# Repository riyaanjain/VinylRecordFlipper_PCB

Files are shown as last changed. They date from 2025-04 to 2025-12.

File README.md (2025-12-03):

# 🎵 Automatic Vinyl Record Flipper

I love vinyl records.

But each side of a 12 inch LP can only store about 20 minutes of music, and I don't necessarily love having to get up to flip the record often. I just wish that, after I put the record on, it would play the entire album.

So, we took matters into our own hands and built an **automatic vinyl record flipper**.

Included are:
- **PCB Design Files**
- **The program code**
- **A picture and video for your enjoyment (have to download the video from Image_and_Video folder🥲)**
- **Design Document**

Hopefully you enjoy it as much as I did!

---

## 🧠 What It Does

This device automatically flips a vinyl record by sending PWM signals to servo motors using an ESP32 microcontroller. It detects the tonearm rest position using a Hall effect sensor, then triggers the motors to lift, rotate, and drop the record back down.

---

## 🖼️ Project Gallery

### 🔧 PCB Preview  
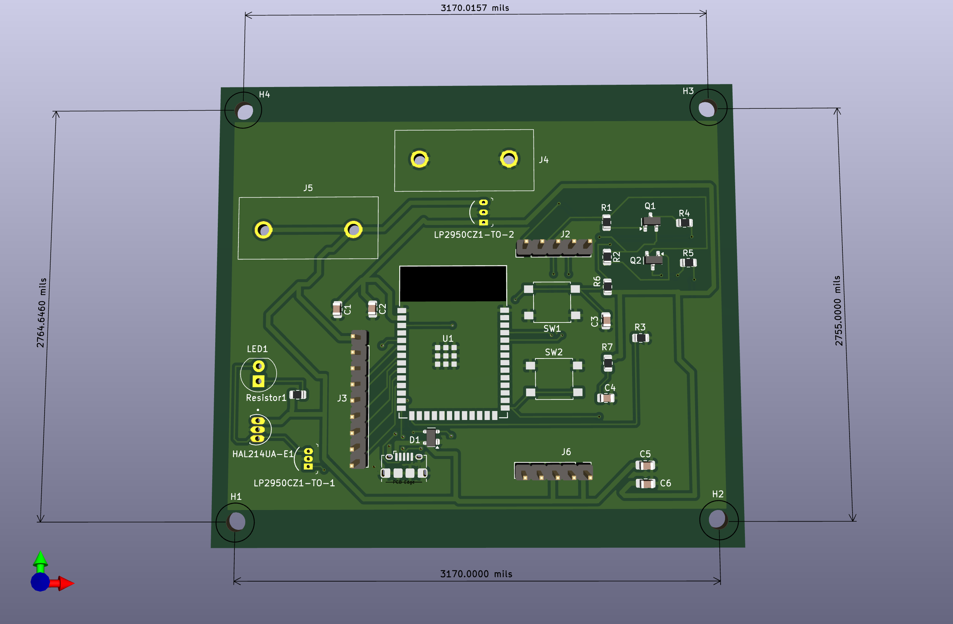
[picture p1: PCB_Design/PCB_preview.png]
PCB Preview


### 📸 Final Project Photo  
Project Photo

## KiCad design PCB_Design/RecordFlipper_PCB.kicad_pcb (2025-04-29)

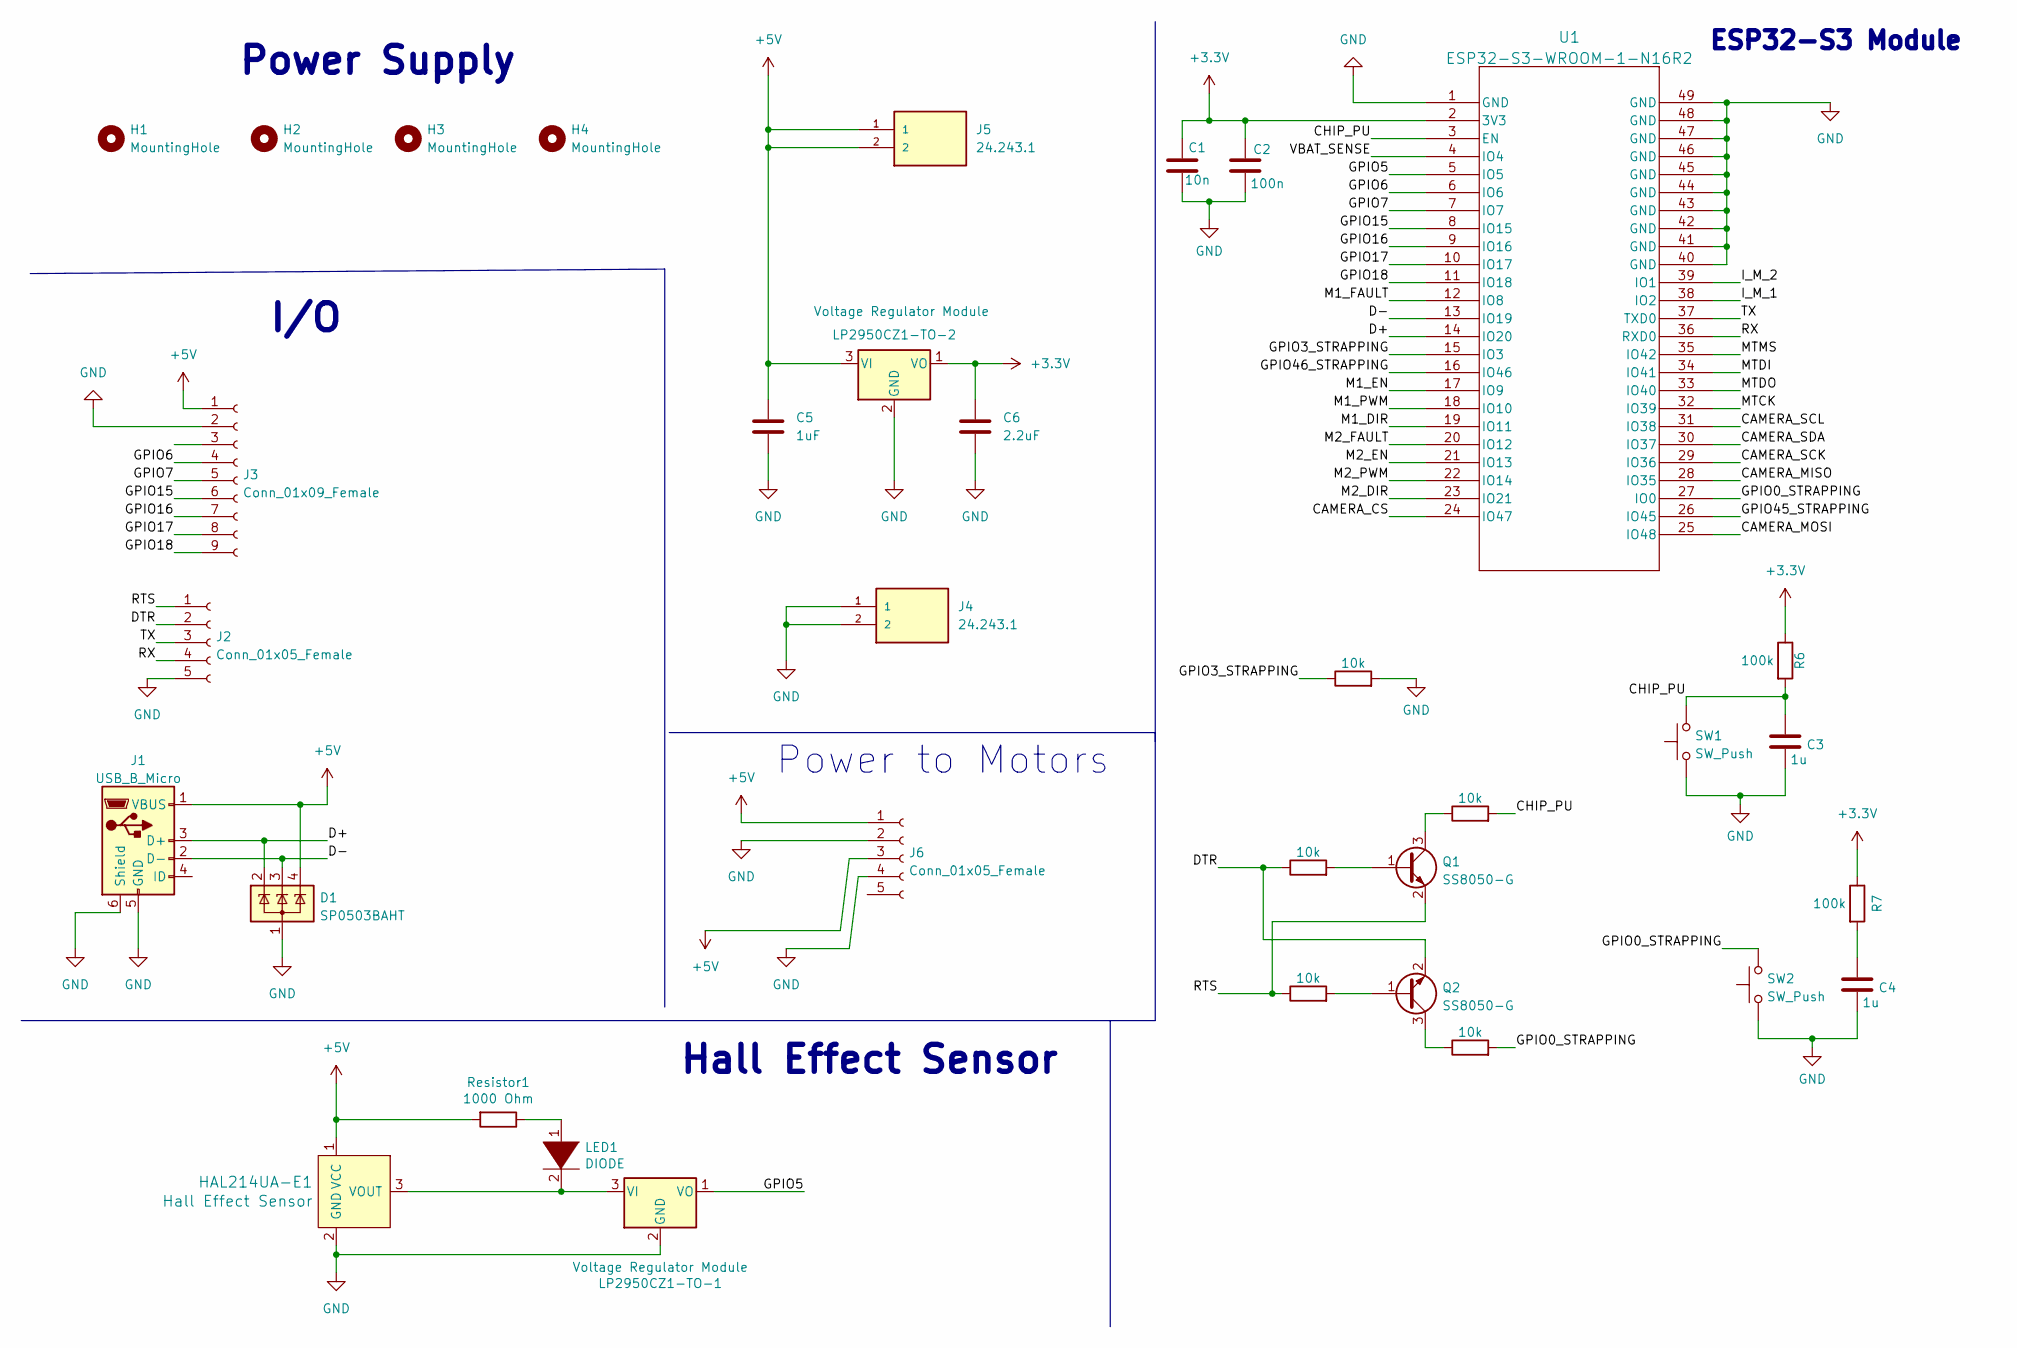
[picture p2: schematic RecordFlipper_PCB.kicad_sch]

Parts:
C1: 10n; C_0805_2012Metric
C2: 100n; C_0805_2012Metric
C3, C4: 1u; C_0805_2012Metric
C5: 1uF; C_0805_2012Metric_Pad1.18x1.45mm_HandSolder
C6: 2.2uF; C_0805_2012Metric_Pad1.18x1.45mm_HandSolder
D1: SP0503BAHT; SOT-143
H1, H2, H3, H4: MountingHole; MountingHole_3.2mm_M3
HAL214UA-E1: Hall Effect Sensor; TO92127P460H470-3; MPN A1326LUA-T; Digi-Key_PN 620-1433-ND
J1: USB_B_Micro; USB_Micro-B_Amphenol_10118194_Horizontal
J2, J6: Conn_01x05_Female; PinHeader_1x05_P2.54mm_Vertical
J3: Conn_01x09_Female; PinHeader_1x09_P2.54mm_Vertical
J4, J5: 24.243.1; 242431; Manufacturer_Part_Number 24.243.1
LED1: DIODE; LED_5mm_Radial
LP2950CZ1-TO-1, LP2950CZ1-TO-2: Voltage Regulator Module; TO-92-3
Q1, Q2: SS8050-G; SOT-23
R1, R2, R3, R4, R5: 10k; R_0805_2012Metric
R6, R7: 100k; R_0805_2012Metric
Resistor1: 1000 Ohm; R_0805_2012Metric
SW1, SW2: SW_Push; SW_SPST_B3S-1000
U1: ESP32-S3-WROOM-1-N16R2; ESP32-S3-WROOM-1_EXP

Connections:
+3.3V: C1.1, C2.1, C6.1, LP2950CZ1-TO-2.1 (VO), R6.1, R7.1, U1.2 (3V3)
+5V: C5.1, D1.4 (K), HAL214UA-E1.1 (VCC), J1.1 (VBUS), J3.1, J5.1, J5.2, J6.1, J6.3, LP2950CZ1-TO-2.3 (VI), Resistor1.2
/CAMERA_CS: U1.24 (IO47)
/CAMERA_MISO: U1.28 (IO35)
/CAMERA_MOSI: U1.25 (IO48)
/CAMERA_SCK: U1.29 (IO36)
/CAMERA_SCL: U1.31 (IO38)
/CAMERA_SDA: U1.30 (IO37)
/CHIP_PU: C3.1, R4.2, R6.2, SW1.2, U1.3 (EN)
/D+: D1.2 (K), J1.3 (D+), U1.14 (IO20)
/D-: D1.3 (K), J1.2 (D-), U1.13 (IO19)
/DTR: J2.2, Q2.2 (E), R1.1
/GPIO0_STRAPPING: R5.2, SW2.2, U1.27 (IO0)
/GPIO3_STRAPPING: R3.1, U1.15 (IO3)
/GPIO5: LP2950CZ1-TO-1.1 (VO), U1.5 (IO5)
/GPIO6: J3.4, U1.6 (IO6)
/GPIO7: J3.5, U1.7 (IO7)
/GPIO15: J3.6, U1.8 (IO15)
/GPIO16: J3.7, U1.9 (IO16)
/GPIO17: J3.8, U1.10 (IO17)
/GPIO18: J3.9, U1.11 (IO18)
/GPIO45_STRAPPING: U1.26 (IO45)
/GPIO46_STRAPPING: U1.16 (IO46)
/I_M_1: U1.38 (IO2)
/I_M_2: U1.39 (IO1)
/M1_DIR: U1.19 (IO11)
/M1_EN: U1.17 (IO9)
/M1_FAULT: U1.12 (IO8)
/M1_PWM: U1.18 (IO10)
/M2_DIR: U1.23 (IO21)
/M2_EN: U1.21 (IO13)
/M2_FAULT: U1.20 (IO12)
/M2_PWM: U1.22 (IO14)
/MTCK: U1.32 (IO39)
/MTDI: U1.34 (IO41)
/MTDO: U1.33 (IO40)
/MTMS: U1.35 (IO42)
/RTS: J2.1, Q1.2 (E), R2.1
/RX: J2.4, U1.36 (RXD0)
/TX: J2.3, U1.37 (TXD0)
/VBAT_SENSE: U1.4 (IO4)
GND: C1.2, C2.2, C3.2, C4.2, C5.2, C6.2, D1.1 (A), HAL214UA-E1.2 (GND), J1.5 (GND), J1.6 (Shield), J2.5, J3.2, J4.1, J4.2, J6.2, J6.4, LP2950CZ1-TO-1.2 (GND), LP2950CZ1-TO-2.2 (GND), R3.2, SW1.1, SW2.1, U1.1 (GND), U1.40 (GND), U1.41 (GND), U1.42 (GND), U1.43 (GND), U1.44 (GND), U1.45 (GND), U1.46 (GND), U1.47 (GND), U1.48 (GND), U1.49 (GND)
unnamed: C4.1, R7.2
unnamed: HAL214UA-E1.3 (VOUT), LED1.2 (A), LP2950CZ1-TO-1.3 (VI)
unnamed: LED1.1 (K), Resistor1.1
unnamed: Q1.1 (B), R1.2
unnamed: Q1.3 (C), R4.1
unnamed: Q2.1 (B), R2.2
unnamed: Q2.3 (C), R5.1

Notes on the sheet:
Hall Effect Sensor
ESP32-S3 Module
Power to Motors
Power Supply
I/O

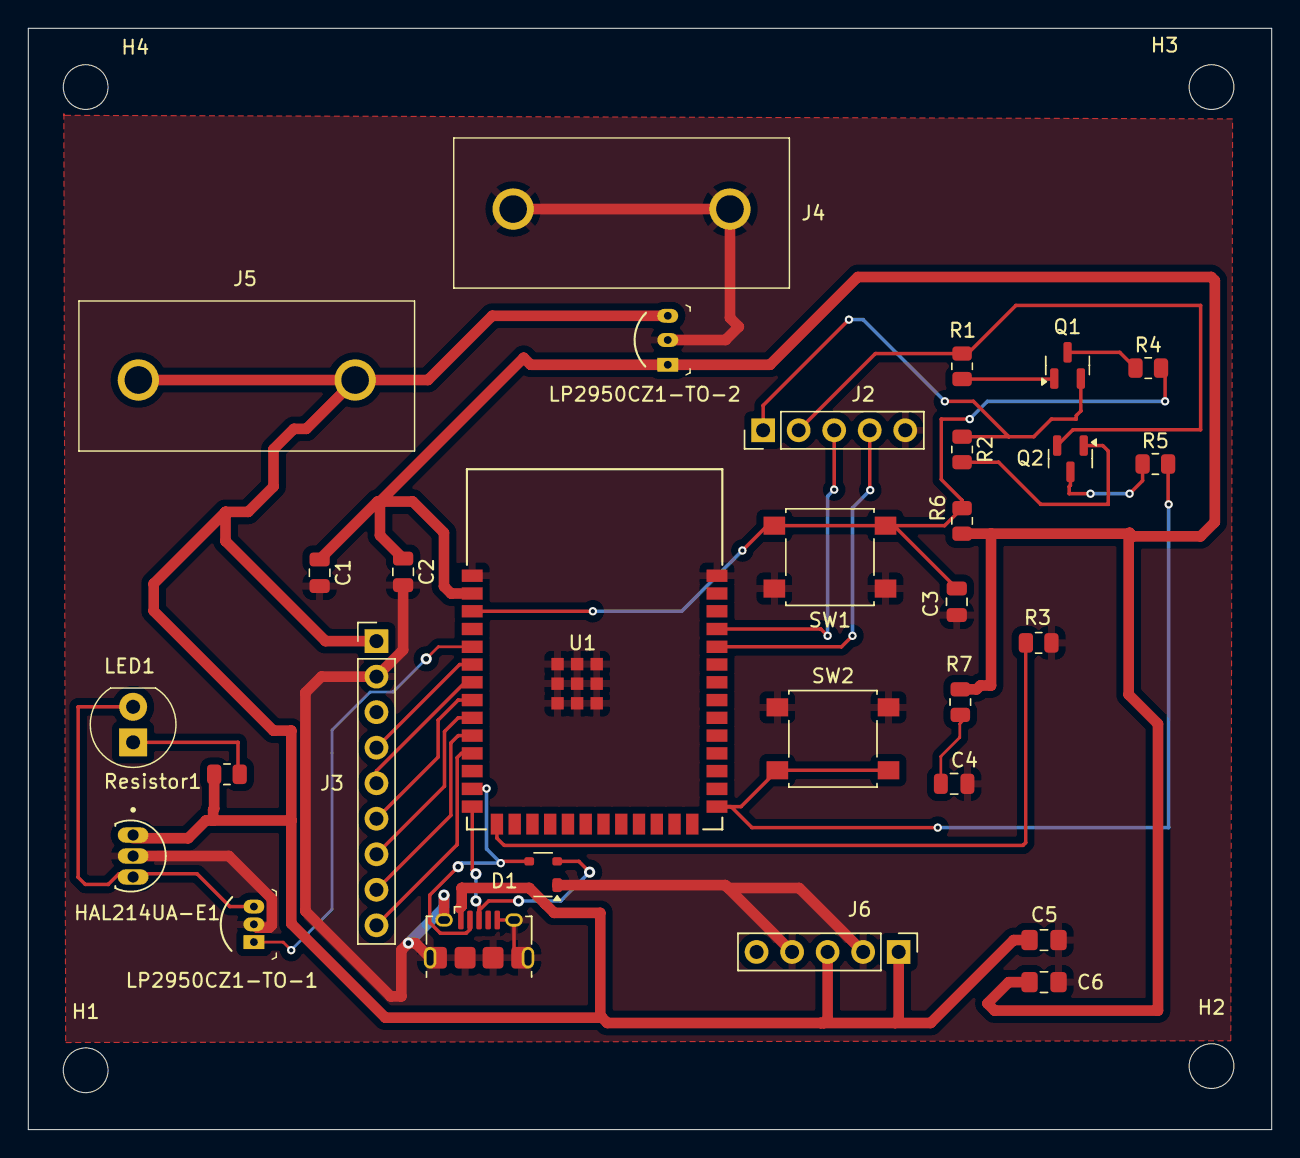
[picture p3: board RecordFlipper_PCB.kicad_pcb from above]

Board: 2 copper layers, 88.9 x 78.7 mm, 34 parts (0 on the bottom side), 26 nets.

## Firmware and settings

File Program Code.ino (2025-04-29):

#include <ESP32Servo.h>

const int hallPin = 5;
const int pink_servoPin = 18; //PINK TOP ONE
const int blue_servoPin = 16;
const int red_servoPin = 15;

Servo pink_servo;
Servo blue_servo;
Servo red_servo;

int lastHallState = HIGH;
bool rest_pos = true;

void setup() {
  pinMode(hallPin, INPUT);
  
  pink_servo.attach(pink_servoPin);
  blue_servo.attach(blue_servoPin);
  red_servo.attach(red_servoPin);

  // Rest position
  delay(500);
  // Old values: Blue=180, Pink=164, Red=82
  // New values: Blue=180, Pink = 162, Red = 84
  blue_servo.write(180);
  delay(500);
  pink_servo.write(161);
  delay(500);
  red_servo.write(84);
  
  Serial.begin(115200);
}

void loop() {
  int currentHallState = digitalRead(hallPin);
  
  if (lastHallState == HIGH && currentHallState == LOW) {
    
    // Grab the record
    for(int pos = 180; pos >= 101; pos-=1){
      blue_servo.write(pos);
      delay(50);
    }

    // Lift the record 
    red_servo.write(80);
    delay(500);
    pink_servo.write(160);
    delay(500);

    delay(200);
    red_servo.write(70);
    delay(200);
    pink_servo.write(150);
    delay(200);
    red_servo.write(60);
    delay(200);
    pink_servo.write(130);
    delay(200);
    red_servo.write(50); //flipping height reached
    delay(200);

    // Flip the record and reseat
    for(int pos = 130; pos >= 50; pos--){
      pink_servo.write(pos);
      delay(20);
    }
    delay(500);
    for(int pos = 50; pos <= 70; pos++){
      red_servo.write(pos);
      delay(20);
    }
    delay(500);
    for(int pos = 50; pos >= 36; pos--){
      pink_servo.write(pos);
      delay(50);
    }
    delay(500);
    
    // Realign, drop, and move away

    for(int pos = 101; pos >= 100; pos-=1){
      blue_servo.write(pos);
      delay(500);
    }
    delay(500);
    
    for(int pos = 70; pos <= 84; pos++){
      red_servo.write(pos);
      delay(20);
    }
    delay(500);

    // Restore to rest

    for(int pos = 100; pos >= 40; pos-=1){
      blue_servo.write(pos);
      delay(20);
    }

    for(int pos = 84; pos >=50; pos--){
      red_servo.write(pos);
      delay(20);
    }

    for(int pos = 40; pos <= 101; pos++){
      blue_servo.write(pos);
      delay(20);
    }

    // Flip back
    for(int pos = 36; pos <= 166; pos++){
      pink_servo.write(pos);
      delay(20);
    }
    delay(500);
    blue_servo.write(180);
    delay(500);
    red_servo.write(84);
  }
  else {
    delay(100);
  }
  lastHallState = currentHallState;
  delay(10);
}
